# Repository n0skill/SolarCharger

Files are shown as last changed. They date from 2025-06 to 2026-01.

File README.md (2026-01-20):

# SolarCharger

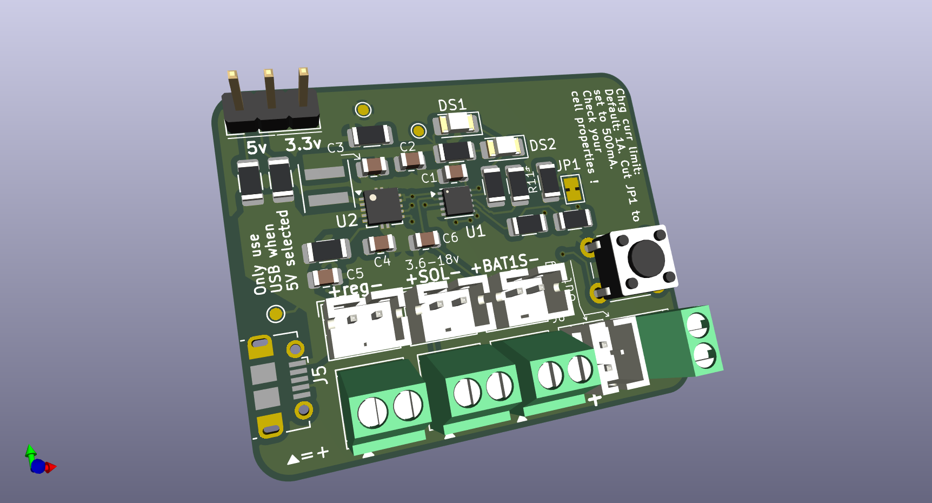
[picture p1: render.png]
3d render of the charger

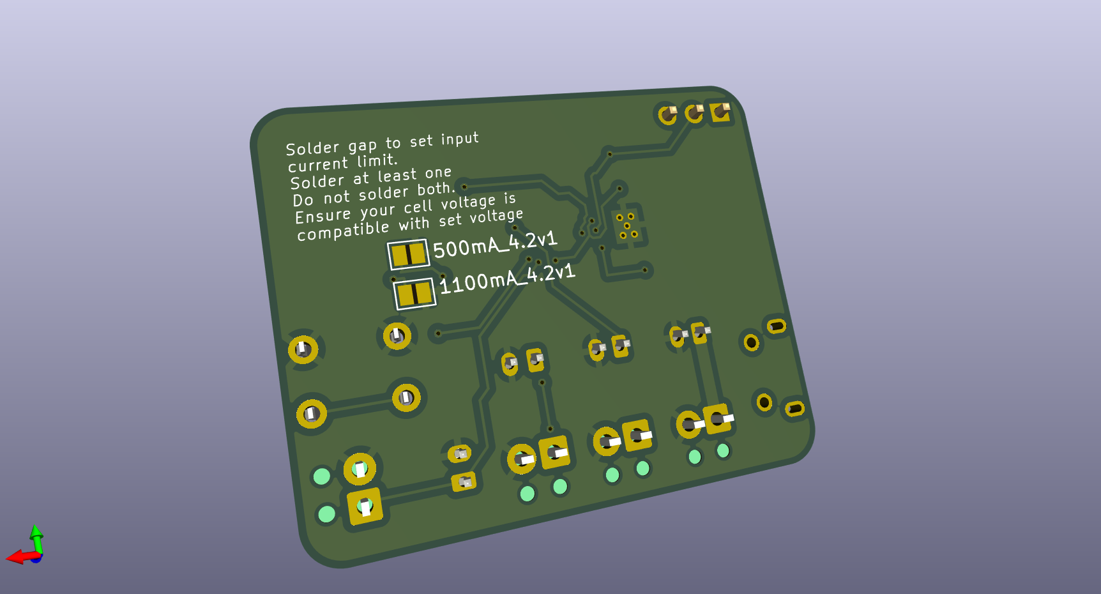
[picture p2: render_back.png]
3d render of the back of the charger


This is a Lithium Ion / Lithium Polymer chemistry battery (4.2V) solar charger. 

The goals are
* To allow the use of a wider range of PV panels
* Ampere-level charging current (currently max. 1A, goal is around 3A)
* To provide a regulated voltage output (3.3v or 5v) at >2A (currently 3.125A)
* To provide an unregulated output
* To provide an USB port output (micro usb) - might change to USB-C in the future

This is done by
* Allowing the use of a larger range of PV solar panels voltages (3.6-18V) 
* Bigger charging current capabilities with a goal of around 3A (currently 1100mA)
* Bigger input current.

## Caracteristics

The goal of this small circuit is not necessarily to be the most efficient.
The primary goal is to be able to support a large variety of panels, while also being able to provide >2A of 5V to the device to power.

### Solar panel support 

The supported panels just have to be within the support of the main IC, the BQ25185.
Therefore supported PV panels MUST provide BETWEEN 3.6 AND 18V at a MINIMUM of 500mA.

Then, depending on your PV panel current capabilities, you *HAVE* to solder *ONE AND ONLY ONE* of the solder jumpers (on the back of the circuit)
* If your solar panel provides 500mA < solar panel current < 1100mA, you HAVE TO solder the 500mA jumper.
  This will limit the input current from the panel to the circuit to 500mA.
* Else, if your panel is able to provide >1100mA, you can still solder the 500mA jumper (this will limit the current). If you wish for more current, you can solder the 1100mA jumper.

### Battery 

This circuit is designed to work with single cell Li-Po batteries ONLY
This means cells with charge a nominal charging voltage of 4.2V.
For the LiPo chemistry, this ONLY works with 1SXP configurations.

A later version will allow a 4.1V charge option to improve cell life at the expense of capacity.

### Charging current

This circuit provides 500mA or 1000mA (default) charging current capabilities. 
Please double check your cells current charging capabilities. 

Your cells MUST be able to sustain a continuous 1A or 500mA charging current.
The charging current is set to 1000mA by default.
To set the charging current to 500mA, cut the JP1 solder jumper on the front right of the board.

### Things left to do
Maybe we should use a BQ24074 instead ? This allows for 1.5A charge current
What about MAX77787 ?

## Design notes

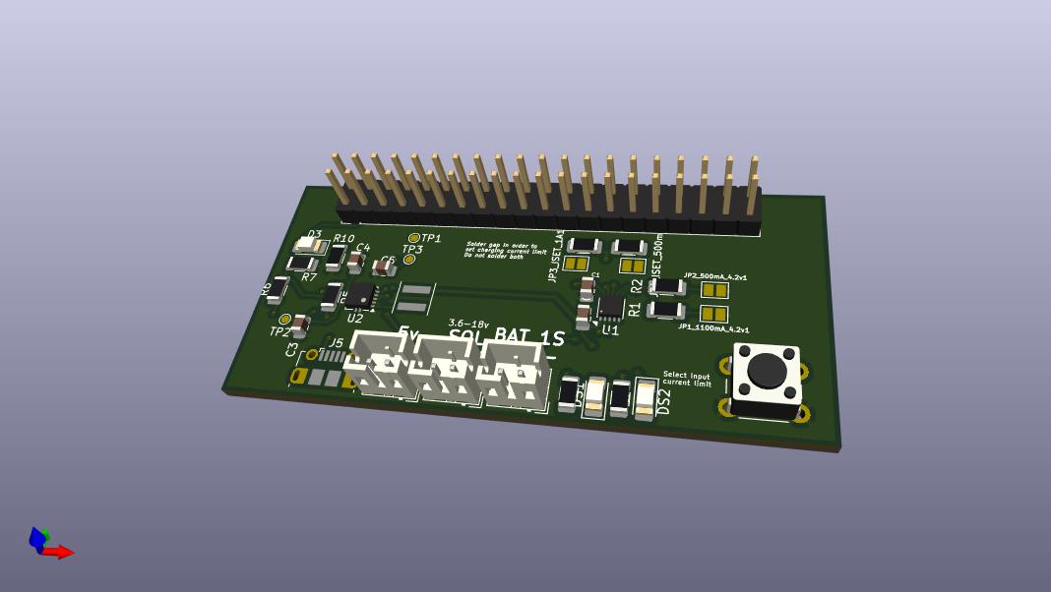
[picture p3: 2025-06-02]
flowsense_charger.jpg

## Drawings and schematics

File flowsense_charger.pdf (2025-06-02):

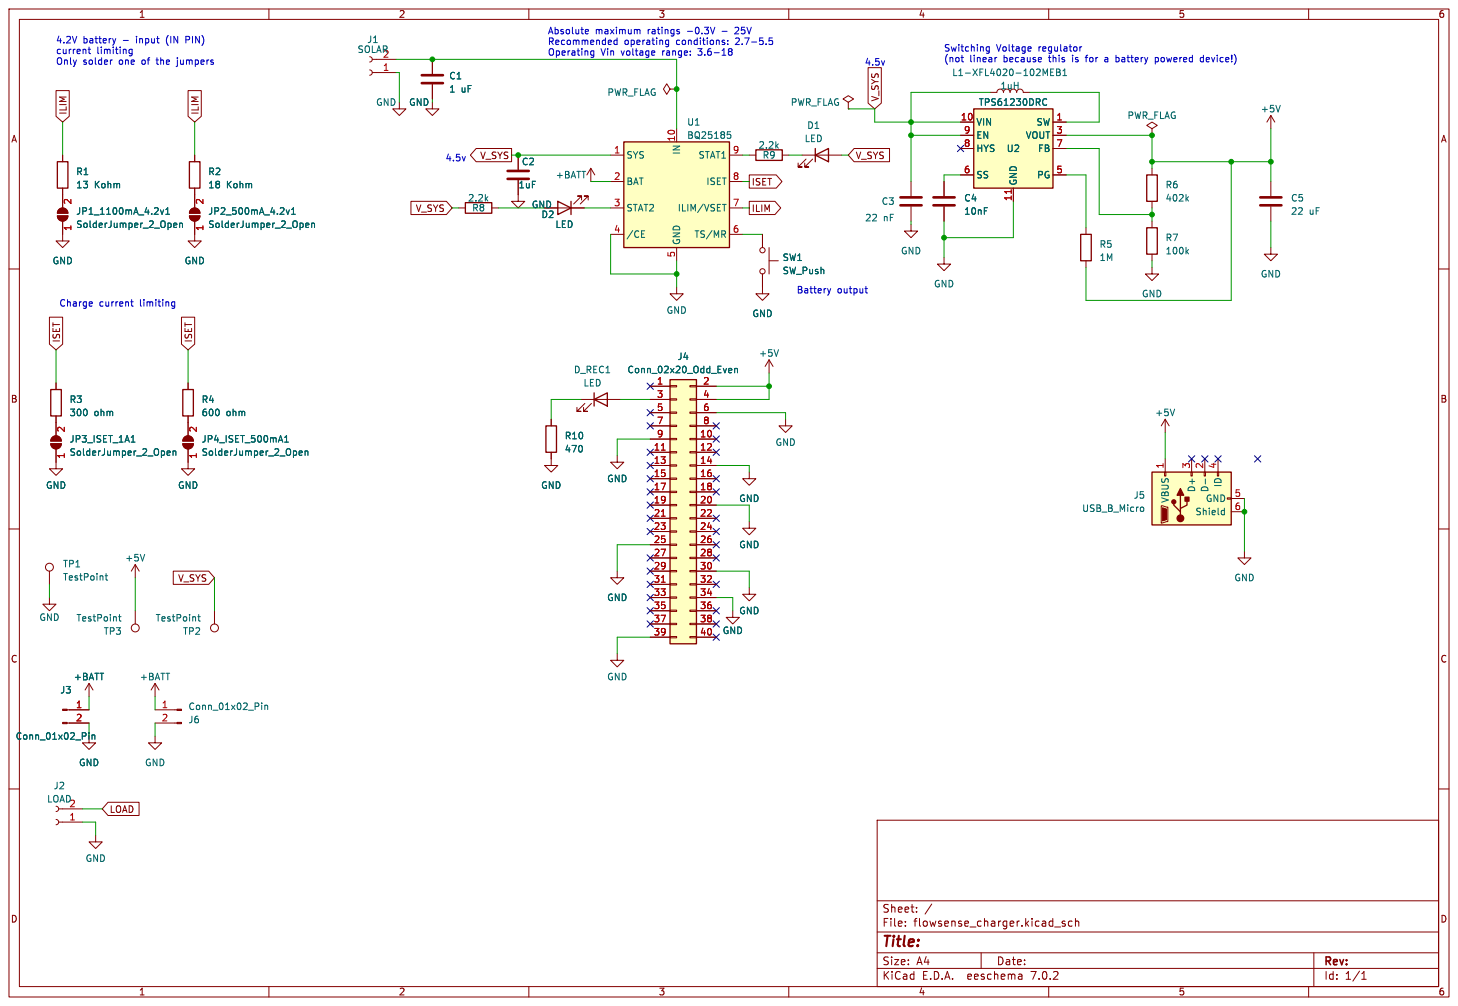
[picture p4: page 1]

4.5v 4.2V battery - input (IN PIN) current limiting

(not linear because this is for a battery powered device!)
L1-XFL4020-102MEB1

Only solder one of the jumpers

Id: 1/1 Title: File: flowsense_charger.kicad_sch Sheet: / GND

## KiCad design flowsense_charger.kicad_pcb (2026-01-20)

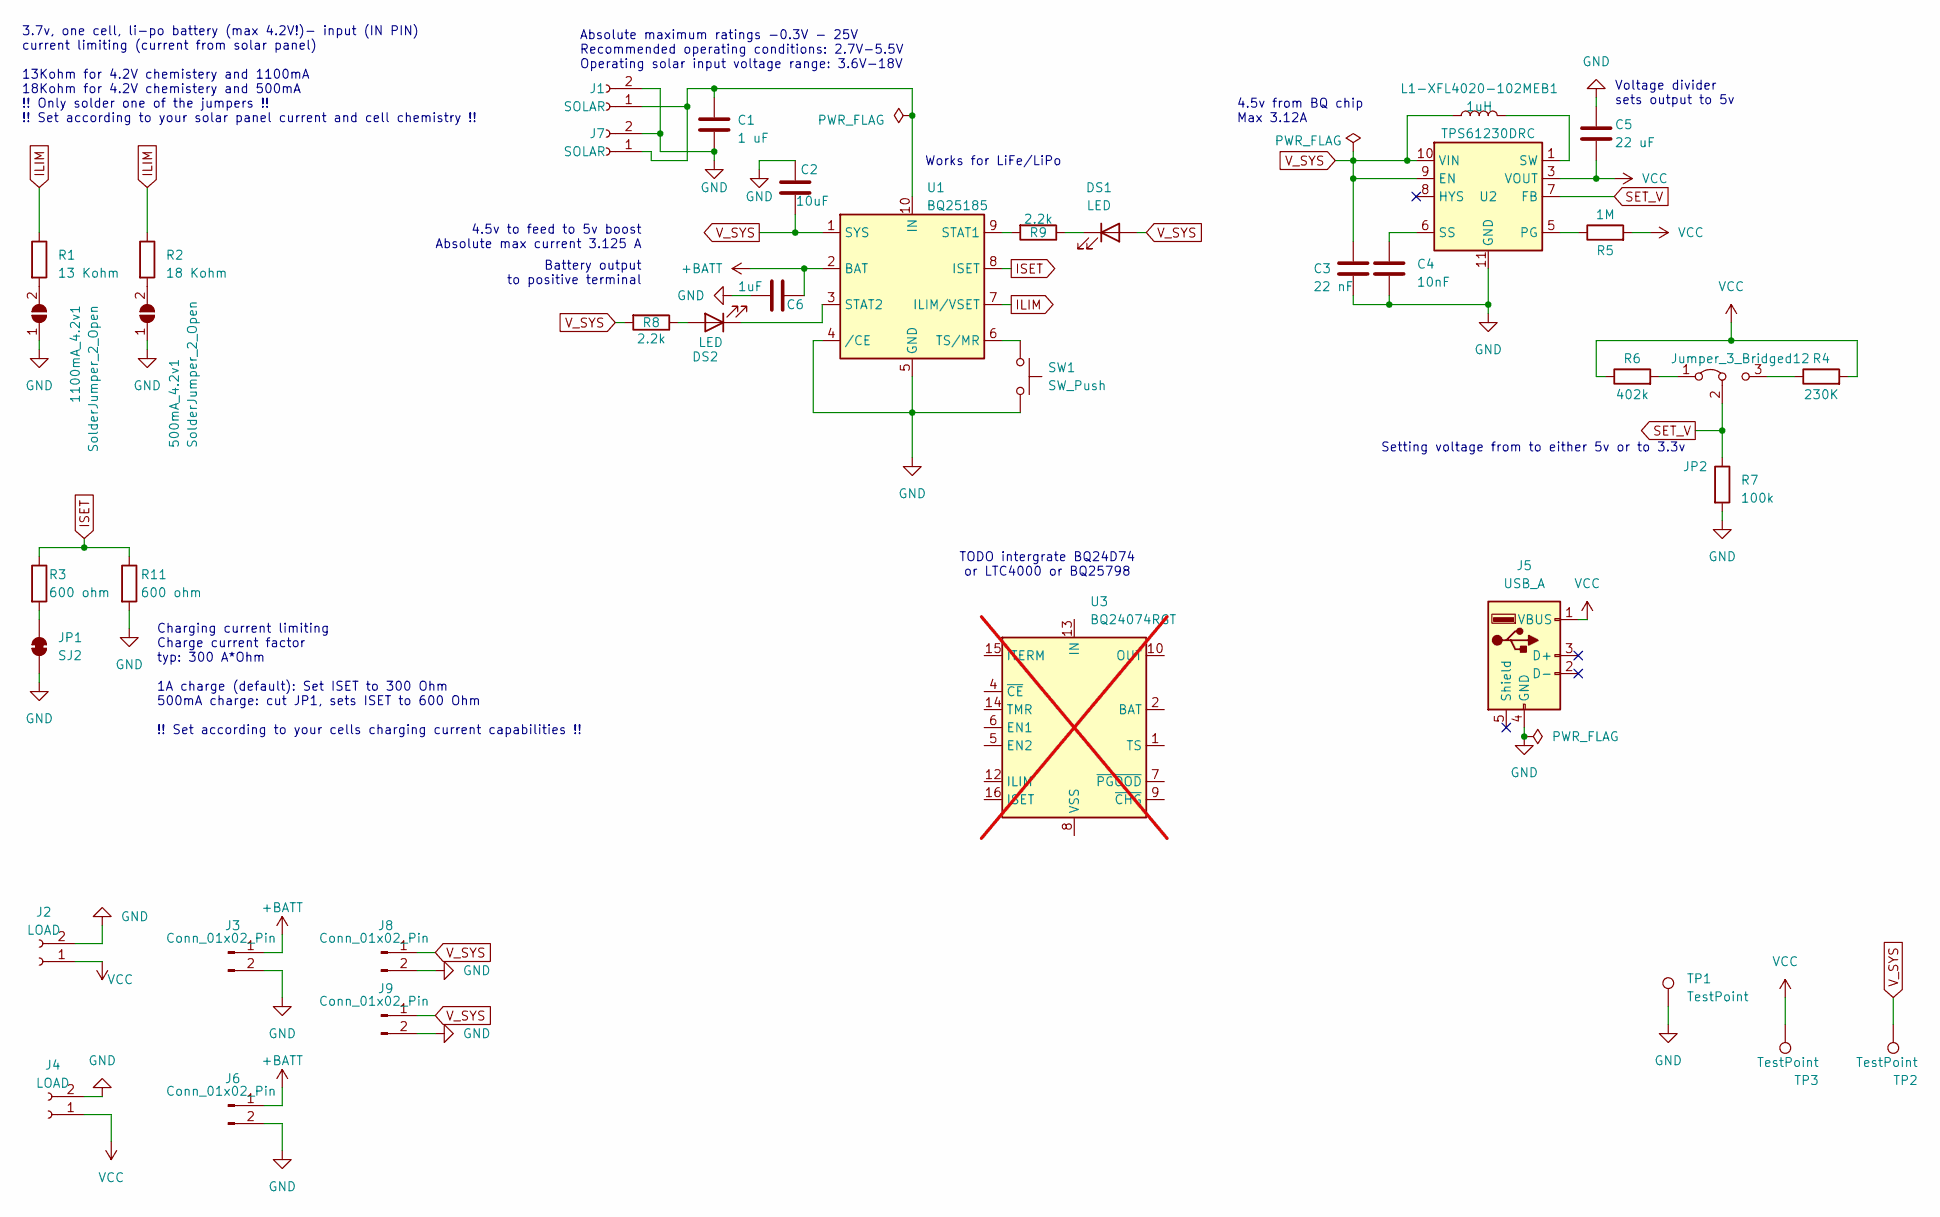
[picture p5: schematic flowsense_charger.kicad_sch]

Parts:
500mA_4.2v1, 1100mA_4.2v1: SolderJumper_2_Open; SolderJumper-2_P1.3mm_Open_Pad1.0x1.5mm
C1: 1 uF; C_0805_2012Metric
C2: 10uF; C_0805_2012Metric
C3: 22 nF; C_0805_2012Metric
C4: 10nF; C_0805_2012Metric
C5: 22 uF; C_0805_2012Metric
C6: 1uF; C_0805_2012Metric
DS1, DS2: LED; LED_1206_3216Metric_Pad1.42x1.75mm_HandSolder
J1: SOLAR; JST_PH_B2B-PH-K_1x02_P2.00mm_Vertical
J2: LOAD; JST_PH_B2B-PH-K_1x02_P2.00mm_Vertical
J3, J8: Conn_01x02_Pin; JST_PH_B2B-PH-K_1x02_P2.00mm_Vertical
J4: LOAD; TerminalBlock_Phoenix_MPT-0,5-2-2.54_1x02_P2.54mm_Horizontal
J5: USB_A; USB_Micro-B_Molex-105017-0001
J6, J9: Conn_01x02_Pin; TerminalBlock_Phoenix_MPT-0,5-2-2.54_1x02_P2.54mm_Horizontal
J7: SOLAR; TerminalBlock_Phoenix_MPT-0,5-2-2.54_1x02_P2.54mm_Horizontal
JP1: SJ2; SolderJumper-2_P1.3mm_Bridged_Pad1.0x1.5mm
JP2: Jumper_3_Bridged12; PinHeader_1x03_P2.54mm_Vertical
L1-XFL4020-102MEB1: 1uH; L_Coilcraft_XxL4020
R1: 13 Kohm; R_1206_3216Metric
R2: 18 Kohm; R_1206_3216Metric
R3, R11: 600 ohm; R_1206_3216Metric
R4: 230K; R_1206_3216Metric
R5: 1M; R_1206_3216Metric
R6: 402k; R_1206_3216Metric
R7: 100k; R_1206_3216Metric
R8, R9: 2.2k; R_1206_3216Metric
SW1: SW_Push; SW_PUSH_6mm
TP1, TP2, TP3: TestPoint; TestPoint_Pad_D1.0mm
U1: BQ25185; WSON-10-1EP_2.5x2.5mm_P0.5mm_EP1.2x2mm
U2: TPS61230DRC; Texas_S-PVSON-N10_ThermalVias
U3: BQ24074RGT; VQFN-16-1EP_3x3mm_P0.5mm_EP1.6x1.6mm; not fitted

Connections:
+BATT: C6.2, J3.1, J6.1, U1.2 (BAT)
GND: 500mA_4.2v1.1 (A), 1100mA_4.2v1.1 (A), C1.2, C2.2, C3.2, C4.2, C5.1, C6.1, J1.2, J2.2, J3.2, J4.2, J5.4 (GND), J6.2, J7.2, J8.2, J9.2, JP1.1 (A), R7.2, R11.2, SW1.2, TP1.1, U1.4 (/CE), U1.5 (GND), U2.11 (GND)
ILIM: R1.1, R2.1, U1.7 (ILIM/VSET)
ISET: R3.1, R11.1, U1.8 (ISET)
unnamed: 500mA_4.2v1.2 (B), R2.2
unnamed: 1100mA_4.2v1.2 (B), R1.2
unnamed: DS1.1 (K), R9.1
unnamed: DS2.2 (A), R8.1
unnamed: DS2.1 (K), U1.3 (STAT2)
unnamed: C1.1, J1.1, J7.1, U1.10 (IN)
unnamed: JP1.2 (B), R3.2
unnamed: JP2.1 (A), R6.2
unnamed: JP2.3 (B), R4.1
unnamed: L1-XFL4020-102MEB1.2, U2.1 (SW), U2.2 (SW)
unnamed: R9.2, U1.9 (STAT1)
unnamed: SW1.1, U1.6 (TS/MR)
unnamed: R5.1, U2.5 (PG)
unnamed: C4.1, U2.6 (SS)
unnamed: U3.2 (BAT), U3.3 (BAT)
unnamed: U3.10 (OUT), U3.11 (OUT)
unnamed: U3.8 (VSS), U3.17 (VSS)
SET_V: JP2.2 (C), R7.1, U2.7 (FB)
VCC: C5.2, J2.1, J4.1, J5.1 (VBUS), R4.2, R5.2, R6.1, TP3.1, U2.3 (VOUT), U2.4 (VOUT)
V_SYS: C2.1, C3.1, DS1.2 (A), J8.1, J9.1, L1-XFL4020-102MEB1.1, R8.2, TP2.1, U1.1 (SYS), U2.9 (EN), U2.10 (VIN)

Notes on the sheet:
Absolute maximum ratings -0.3V - 25V Recommended operating conditions: 2.7V-5.5V Operating solar input voltage range: 3.6V-18V
Charging current limiting Charge current factor typ: 300 A*Ohm 1A charge (default): Set ISET to 300 Ohm 500mA charge: cut JP1, sets ISET to 600 Ohm !! Set according to your cells charging current capabilities !!
3.7v, one cell, li-po battery (max 4.2V!)- input (IN PIN) current limiting (current from solar panel) 13Kohm for 4.2V chemistery and 1100mA 18Kohm for 4.2V chemistery and 500mA !! Only solder one of the jumpers !! !! Set according to your solar panel current and cell chemistry !!
Voltage divider sets output to 5v
4.5v from BQ chip Max 3.12A
TODO intergrate BQ24D74 or LTC4000 or BQ25798
4.5v to feed to 5v boost Absolute max current 3.125 A
Setting voltage from to either 5v or to 3.3v
Battery output to positive terminal
Works for LiFe/LiPo

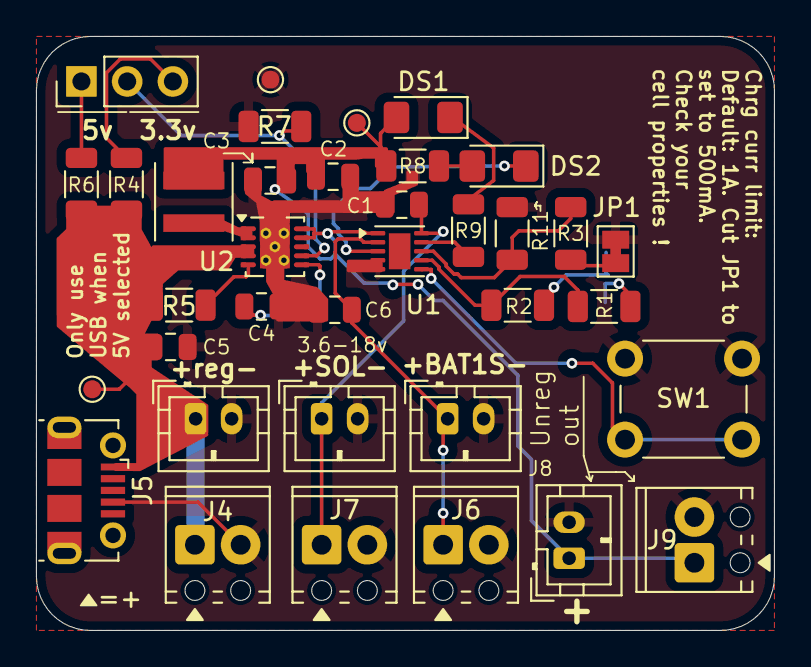
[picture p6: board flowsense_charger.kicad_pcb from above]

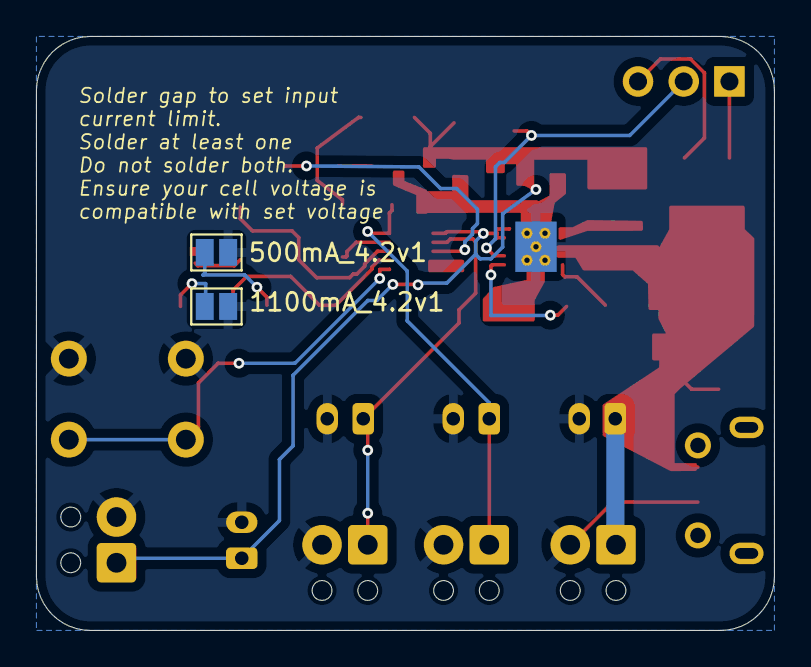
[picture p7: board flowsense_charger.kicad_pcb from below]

Board: 2 copper layers, 41.0 x 33.0 mm, 38 parts (2 on the bottom side), 21 nets.

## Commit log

2025-06-02 Adds initial files
    [flowsense-B_Cu.gbl, flowsense-B_Cu.gbr, flowsense-B_Mask.gbr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]
2026-01-07 Scheme: Fixes capacitor issue on PIN1 SYS of U1. Adds decoupler 1uF on PIN2 BAT of U1. Clarifies text
    [flowsense_charger.kicad_pcb, flowsense_charger.kicad_sch]
2026-01-07 Writing more info on the readme
    [flowsense_charger.kicad_sch]
2026-01-09 Starts implementing non-regulated output, and alternative 3.3v regulated output.
    [flowsense_charger.kicad_pcb, flowsense_charger.kicad_sch]
2026-01-09 Rearrange text on schematic a bit
    [flowsense_charger.kicad_pcb, flowsense_charger.kicad_sch]
2026-01-16 Layout all components on a single face for easier manufacturing
    [flowsense_charger.kicad_pcb, flowsense_charger.kicad_sch]
2026-01-19 Removes old design file. Updates current file with design that passes DRC.
    [flowsense-B_Cu.gbl, flowsense-B_Cu.gbr, flowsense-B_Mask.gbr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]
2026-01-20 Updates readme with latest info. Updates silkscreen infos. Ignore thermal relief warnings. Champfer board edges
    [flowsense_charger.kicad_pcb]
2026-01-20 Apply last commit chages to the non-cache files. Error check passes.
    [flowsense_charger.kicad_pcb]
2026-01-20 Adds updated renders of the board, now including back side
